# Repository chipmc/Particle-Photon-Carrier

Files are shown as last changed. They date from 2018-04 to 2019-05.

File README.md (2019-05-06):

# Particle-Photon-Carrier
EAGLE design files for the Particle Carrier

This is a project that implements a smart watering system for back-deck gardening.  I use the Particle platform
to moniror the soil moisture and the near-tearm weather forecast to amek intelligent decisions on when and how
much to water.  I have used this system on my own garden for the past three years and each year it gets a little better.

Please see the full project description and documentation (hardware and software) on Hackster.io.  

Here is the project link: https://www.hackster.io/chipmc/smart-and-safe-outdoor-plant-watering-system-new-for-2018

And keep an eye out for annual updates.

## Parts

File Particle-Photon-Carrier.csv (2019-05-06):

Part | Value | Device | Package | Description | Digikey Part Number
ANALOG |  | CONN_083.5MM-8 | SCREWTERMINAL-3.5MM-8 | 3.5mm horizontal with board screw terminal | 277-1725-ND
C1 | 1.0uF | 1.0UF-0805-25V-10% | 805 | 1µF ceramic capacitors | 311-1365-1-ND
D1 | 3A/40V/500mV | DIODE-SCHOTTKY-B340A | SMA-DIODE | Schottky diode | MBR0540CT-ND
D2 | 3A/40V/500mV | DIODE-SCHOTTKY-B340A | SMA-DIODE | Schottky diode | MBR0540CT-ND
DIGITAL |  | CONN_083.5MM-8 | SCREWTERMINAL-3.5MM-8 | 3.5mm horizontal with board screw terminal | 277-1725-ND
F1 | 500mA - FAST BLOW | PPTC_HALF-AMP | 1206 | Resettable Fuse PPTC | F2569CT-ND
F2 | 500mA - FAST BLOW | PPTC_HALF-AMP | 1206 | Resettable Fuse PPTC | F2569CT-ND
F3 | 1.5A - SLOW BLOW | PPTC_HALF-AMP | 1206 | Resettable Fuse PPTC | F3156CT-ND
F4 | 500mA - FAST BLOW | PPTC_HALF-AMP | 1206 | Resettable Fuse PPTC | F2569CT-ND
J1 |  | CONN_023.5MM | SCREWTERMINAL-3.5MM-2 | Multi connection point. Often used as Generic Header-pin footprint for 0.1 inch spaced/style header connections | 277-15481-ND
J2 | 5V @ 2A | JST_2MM_MALE | JST-2-SMD | JST 2MM MALE RA CONNECTOR | 455-1749-1-ND
J3 |  | CONN_03LOCK | 1X03_LOCK | Female 0.1” header - optional in case you don’t want to solder the DC-Dco converter directly to the board | HDR100IMP40F-G-V-TH-ND
J4 |  | CONN_023.5MM | SCREWTERMINAL-3.5MM-2 | 3.5mm horizontal with board screw terminal | 277-15481-ND
LED1 |  | LEDCHIPLED_0805 | CHIPLED_0805 | LED | 475-1410-1-ND
LED2 |  | LEDCHIPLED_0805 | CHIPLED_0805 | LED | 475-1410-1-ND
PHOTON | PHOTON_WITH_HEADERS | PHOTON_WITH_HEADERS | PHOTON | Particle Photon Wi-Fi through-hole development board footprint | HDR100IMP40F-G-V-TH-ND
R1 | 100k | R-US_R0805 | R0805 | RESISTOR, American symbol | RMCF0805FT100KCT-ND
R2 | 25k | R-US_R0805 | R0805 | RESISTOR, American symbol | A124124CT-ND
R3 | 1k | R-US_R0805 | R0805 | RESISTOR, American symbol | 311-1.0KCRCT-ND
R4 | 1k | R-US_R0805 | R0805 | RESISTOR, American symbol | 311-1.0KCRCT-ND
R5 | 100k | R-US_R0805 | R0805 | RESISTOR, American symbol | RMCF0805FT100KCT-ND
R6 | 1k | R-US_R0805 | R0805 | RESISTOR, American symbol | 311-1.0KCRCT-ND
R7 | 100k | R-US_R0805 | R0805 | RESISTOR, American symbol | RMCF0805FT100KCT-ND
R8 | 1k | R-US_R0805 | R0805 | RESISTOR, American symbol | 311-1.0KCRCT-ND
R9 | 1k | R-US_R0805 | R0805 | RESISTOR, American symbol | 311-1.0KCRCT-ND
R10 | 1k | R-US_R0805 | R0805 | RESISTOR, American symbol | 311-1.0KCRCT-ND
R11 | 1k | R-US_R0805 | R0805 | RESISTOR, American symbol | 311-1.0KCRCT-ND
R12 | 1k | R-US_R0805 | R0805 | RESISTOR, American symbol | 311-1.0KCRCT-ND
R13 | 4.7k | R-US_R0805 | R0805 | RESISTOR, American symbol | 311-4.70kCRCT-ND
R14 | 4.7k | R-US_R0805 | R0805 | RESISTOR, American symbol | 311-4.70kCRCT-ND
R15 | 1k | R-US_R0805 | R0805 | RESISTOR, American symbol | 311-1.0KCRCT-ND
R16 | 1k | R-US_R0805 | R0805 | RESISTOR, American symbol | 311-1.0KCRCT-ND
R17 | 1k | R-US_R0805 | R0805 | RESISTOR, American symbol | 311-1.0KCRCT-ND
R18 | 1k | R-US_R0805 | R0805 | RESISTOR, American symbol | 311-1.0KCRCT-ND
R19 | 1k | R-US_R0805 | R0805 | RESISTOR, American symbol | 311-1.0KCRCT-ND
SWITCH | IRF6201PBF | IRF6201PBF | SO8-GW300 | IRF6201 - N-MOSFET | IRF6201PBF-ND
SWITCH1 | IRF6201PBF | IRF6201PBF | SO8-GW300 | IRF6201 - N-MOSFET | IRF6201PBF-ND
TVS-DIODE | D5V0L4B5TS | D5V0L4B5TS | SOT-23-5 | 4 CHANNEL LOW CAPACITANCE BI-DIRECTIONAL TVS ARRAY | D5V0L4B5TS-7DICT-ND
V1 | VC080505C150DP | VARISTOR | 805 | Varistor for Circuit protection | 478-2507-1-ND
V2 | VC080505C150DP | VARISTOR | 805 | Varistor for Circuit protection | 478-2507-1-ND
V3 | VC080505C150DP | VARISTOR | 805 | Varistor for Circuit protection | 478-2507-1-ND
V4 | VC080505C150DP | VARISTOR | 805 | Varistor for Circuit protection | 478-2507-1-ND
WATCHDOG | TPL5010 | TPL5010 | TSOT-23 | Watchdog Timer IC | 296-44392-1-ND
DC-DC Converter | OKI-78SR-5/1.5-W36-C | DC-DC Converter | 0.1” Male headers | 12V to 5V High Effifiency Buck Converter | 811-2196-5-ND

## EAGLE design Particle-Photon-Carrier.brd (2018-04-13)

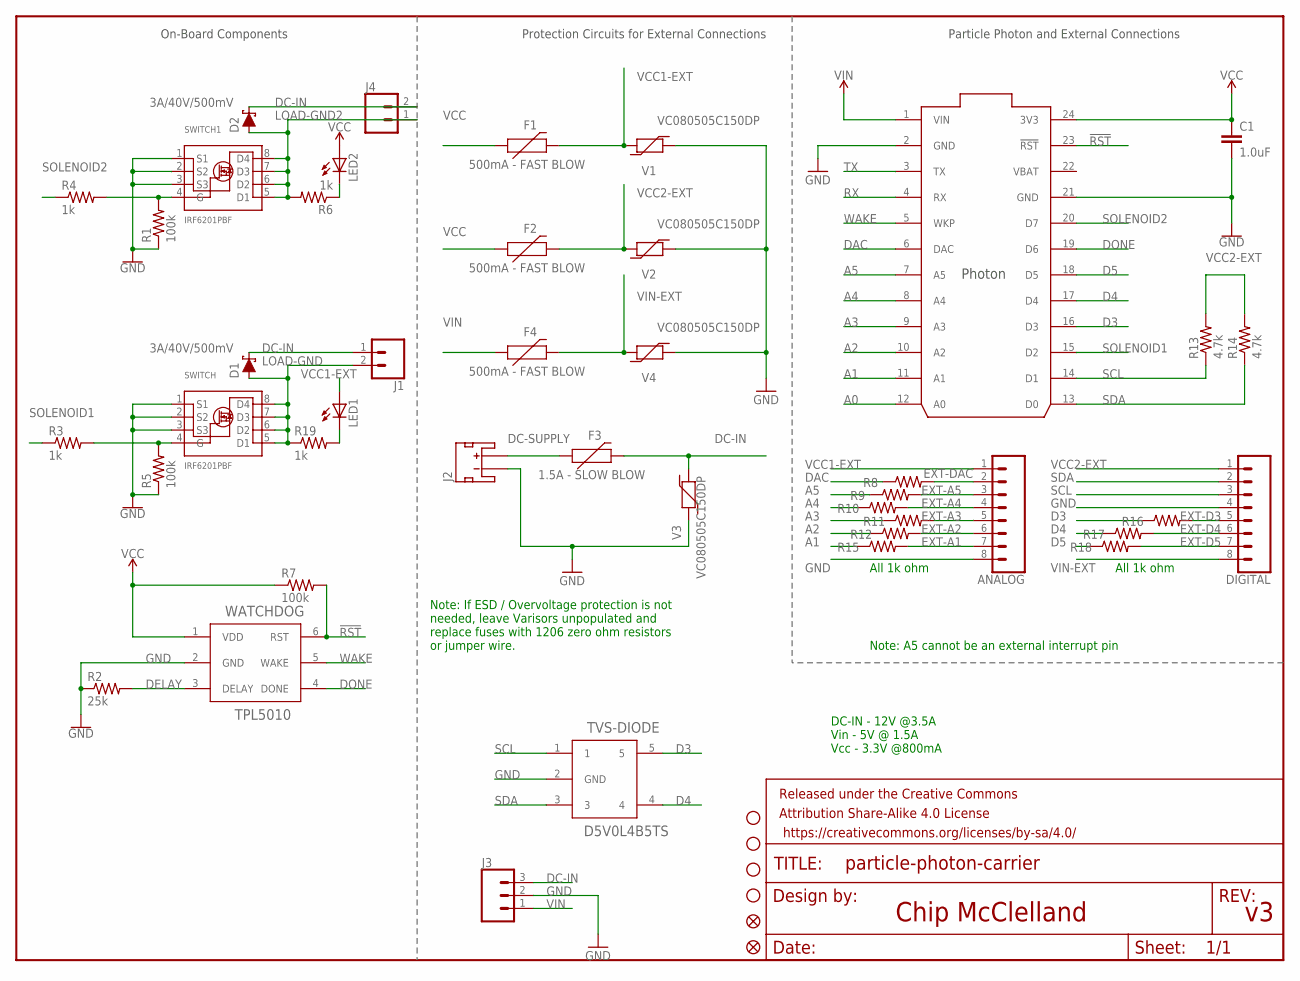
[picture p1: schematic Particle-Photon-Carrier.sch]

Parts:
ANALOG: CONN_083.5MM-8; SCREWTERMINAL-3.5MM-8
C1: 1.0uF; 0805
D1, D2: 3A/40V/500mV; SMA-DIODE
DIGITAL: CONN_083.5MM-8; SCREWTERMINAL-3.5MM-8
F1, F2, F4: 500mA - FAST BLOW; 1206
F3: 1.5A - SLOW BLOW; 1206
FD1, FD2: FIDUCIALUFIDUCIAL; FIDUCIAL-MICRO
FRAME1: FRAME-LETTER; CREATIVE_COMMONS
J1, J4: CONN_023.5MM; SCREWTERMINAL-3.5MM-2
J2: 5V @ 2A; JST-2-SMD
J3: CONN_03LOCK; 1X03_LOCK
JP3, JP4, JP5, JP6: STAND-OFF
LED1, LED2: LEDCHIPLED_0805; CHIPLED_0805
PHOTON: PHOTON_WITH_HEADERS; PHOTON
R1, R5, R7: 100k; R0805
R2: 25k; R0805
R3, R4, R6, R8, R9, R10, R11, R12, R15, R16, R17, R18, R19: 1k; R0805
R13, R14: 4.7k; R0805
SWITCH, SWITCH1: IRF6201PBF; SO8-GW300
TVS-DIODE: D5V0L4B5TS; SOT-23-5
V1, V2, V3, V4: VC080505C150DP; 0805
WATCHDOG: TPL5010; TSOT-23

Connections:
!RST: PHOTON.23 (!RST), R7.2, WATCHDOG.6 (RST)
A0: PHOTON.12 (A0)
A1: PHOTON.11 (A1), R15.1
A2: PHOTON.10 (A2), R12.1
A3: PHOTON.9 (A3), R11.1
A4: PHOTON.8 (A4), R10.1
A5: PHOTON.7 (A5), R9.1
D3: PHOTON.16 (D3), R16.1, TVS-DIODE.5
D4: PHOTON.17 (D4), R17.1, TVS-DIODE.4
D5: PHOTON.18 (D5), R18.1
DAC: PHOTON.6 (DAC), R8.1
DC-IN: D1.C, D2.C, F3.2, J1.1, J3.3, J4.2, V3.2
DC-SUPPLY: F3.1, J2.2 (+)
DELAY: R2.2, WATCHDOG.3 (DELAY)
DONE: PHOTON.19 (D6), WATCHDOG.4 (DONE)
EXT-A1: ANALOG.7, R15.2
EXT-A2: ANALOG.6, R12.2
EXT-A3: ANALOG.5, R11.2
EXT-A4: ANALOG.4, R10.2
EXT-A5: ANALOG.3, R9.2
EXT-D3: DIGITAL.5, R16.2
EXT-D4: DIGITAL.6, R17.2
EXT-D5: DIGITAL.7, R18.2
EXT-DAC: ANALOG.2, R8.2
GATE: R3.2, R5.2, SWITCH.4 (G)
GATE1: R1.2, R4.2, SWITCH1.4 (G)
GND: ANALOG.8, C1.2, DIGITAL.4, J2.1 (-), J3.2, PHOTON.2 (GND), PHOTON.21 (GND), R1.1, R2.1, R5.1, SWITCH.1 (S1), SWITCH.2 (S2), SWITCH.3 (S3), SWITCH1.1 (S1), SWITCH1.2 (S2), SWITCH1.3 (S3), TVS-DIODE.2 (GND), V1.1, V2.1, V3.1, V4.1, WATCHDOG.2 (GND)
LOAD-GND: D1.A, J1.2, R19.1, SWITCH.5 (D1), SWITCH.6 (D2), SWITCH.7 (D3), SWITCH.8 (D4)
LOAD-GND2: D2.A, J4.1, R6.2, SWITCH1.5 (D1), SWITCH1.6 (D2), SWITCH1.7 (D3), SWITCH1.8 (D4)
unnamed: LED2.C, R6.1
unnamed: LED1.C, R19.2
RX: PHOTON.4 (RX)
SCL: DIGITAL.3, PHOTON.14 (D1), R13.1, TVS-DIODE.1
SDA: DIGITAL.2, PHOTON.13 (D0), R14.1, TVS-DIODE.3
SOLENOID1: PHOTON.15 (D2), R3.1
SOLENOID2: PHOTON.20 (D7), R4.1
TX: PHOTON.3 (TX)
VBAT: PHOTON.22 (VBAT)
VCC: C1.1, F1.1, F2.1, LED2.A, PHOTON.24 (3V3), R7.1, WATCHDOG.1 (VDD)
VCC1-EXT: ANALOG.1, F1.2, LED1.A, V1.2
VCC2-EXT: DIGITAL.1, F2.2, R13.2, R14.2, V2.2
VIN: F4.1, J3.1, PHOTON.1 (VIN)
VIN-EXT: DIGITAL.8, F4.2, V4.2
WAKE: PHOTON.5 (WKP), WATCHDOG.5 (WAKE)

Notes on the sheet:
Chip McClelland
Note: A5 cannot be an external interrupt pin
DC-IN - 12V @3.5A Vin - 5V @ 1.5A Vcc - 3.3V @800mA
Protection Circuits for External Connections
On-Board Components
Particle Photon and External Connections
Note: If ESD / Overvoltage protection is not needed, leave Varisors unpopulated and replace fuses with 1206 zero ohm resistors or jumper wire.
All 1k ohm

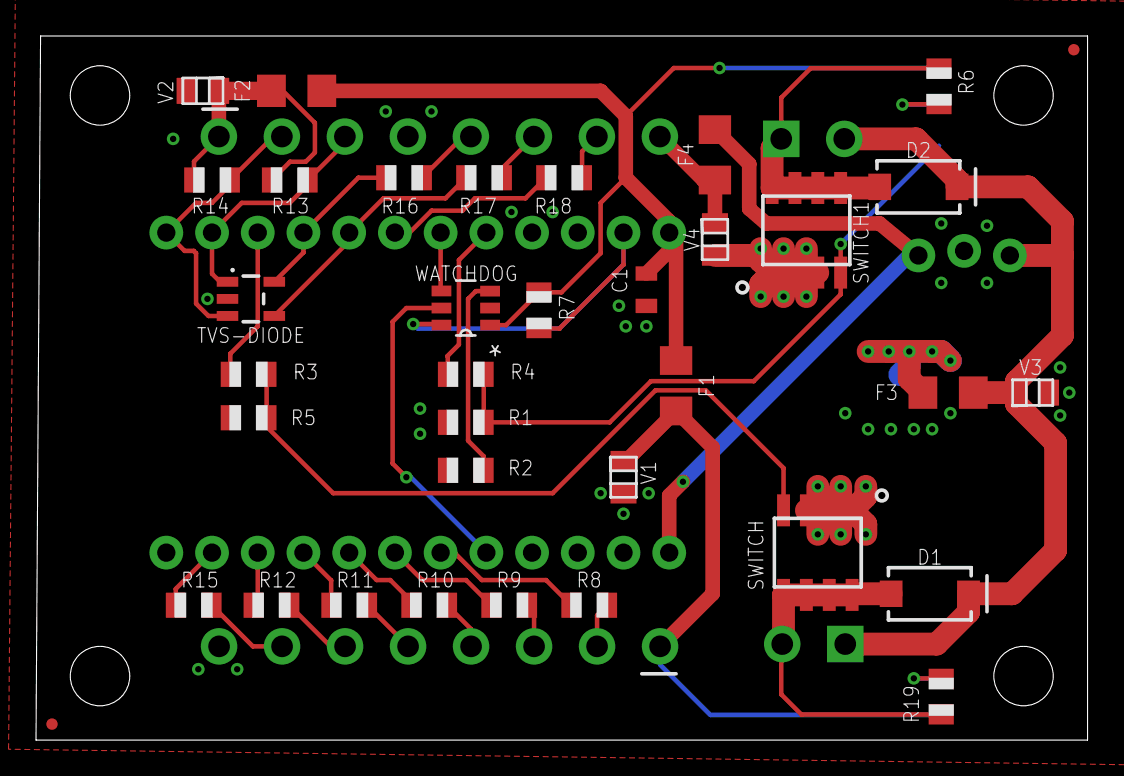
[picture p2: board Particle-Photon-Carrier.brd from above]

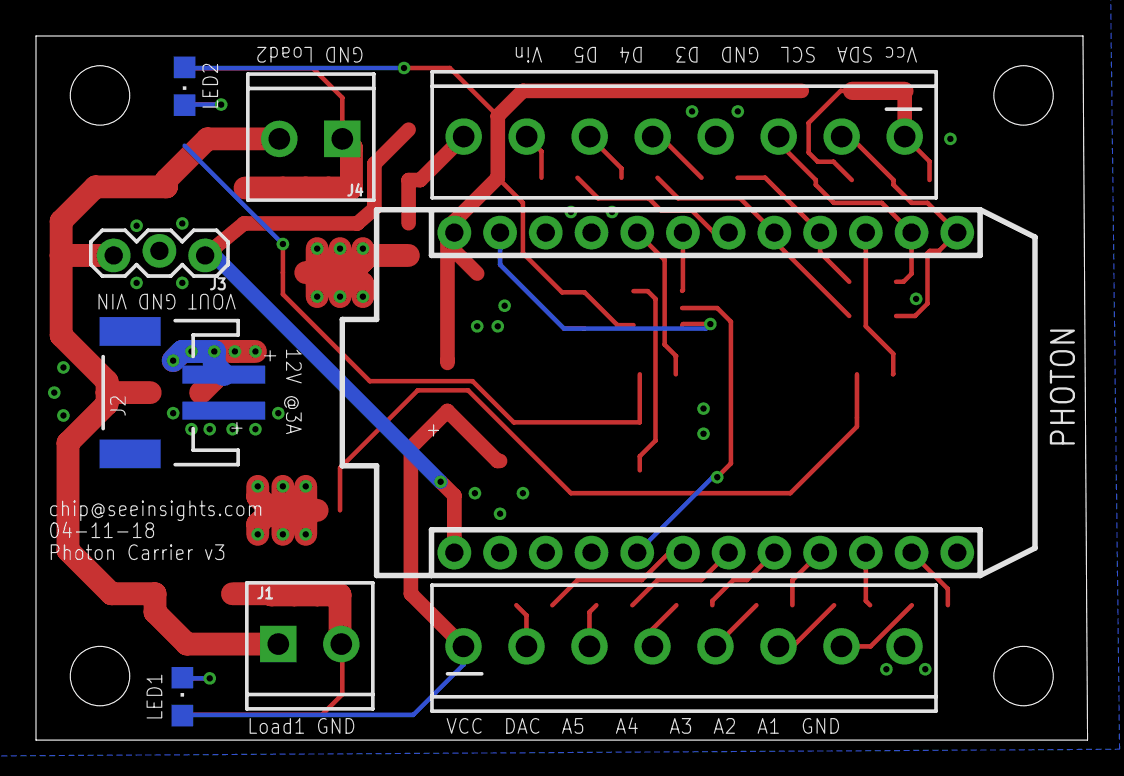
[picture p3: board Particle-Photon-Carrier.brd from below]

Board: 2 copper layers, 58.4 x 39.1 mm, 50 parts (9 on the bottom side), 40 nets.

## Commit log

2017-08-23 Carrier board for the Particle Photon
    [Particle-Photon-Carrier.brd, Particle-Photon-Carrier.sch]
2017-08-23 Latest AquaMaster Carrier Board - sent to OSHPark today
    [AquaMaster-Carrier.brd, AquaMaster-Carrier.sch]
2017-11-08 Added BOM
    [AquaMaster-Carrier.brd, AquaMaster-Carrier.csv, AquaMaster-Carrier.sch]
2017-11-08 Updated BOM
    [AquaMaster-Carrier.csv]
2017-11-08 Added Header Part numbers
    [AquaMaster-Carrier.csv]
2018-04-13 v3 of the AquaMaster
    For Spring 2018
    [Particle-Photon-Carrier.brd, Particle-Photon-Carrier.sch]
2018-04-13 New files
    [Particle-Photon-Carrier.brd, Particle-Photon-Carrier.sch]
2019-05-01 Deleted old BOM and added the new
    [AquaMaster-Carrier.csv, Particle-Photon-Carrier.csv]

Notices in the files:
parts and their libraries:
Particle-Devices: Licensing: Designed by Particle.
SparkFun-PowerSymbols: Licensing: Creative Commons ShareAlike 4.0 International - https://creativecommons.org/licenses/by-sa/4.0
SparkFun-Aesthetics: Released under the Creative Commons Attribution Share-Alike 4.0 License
